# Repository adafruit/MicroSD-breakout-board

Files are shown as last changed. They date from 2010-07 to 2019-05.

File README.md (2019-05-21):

## Adafruit MicroSD breakout board PCB
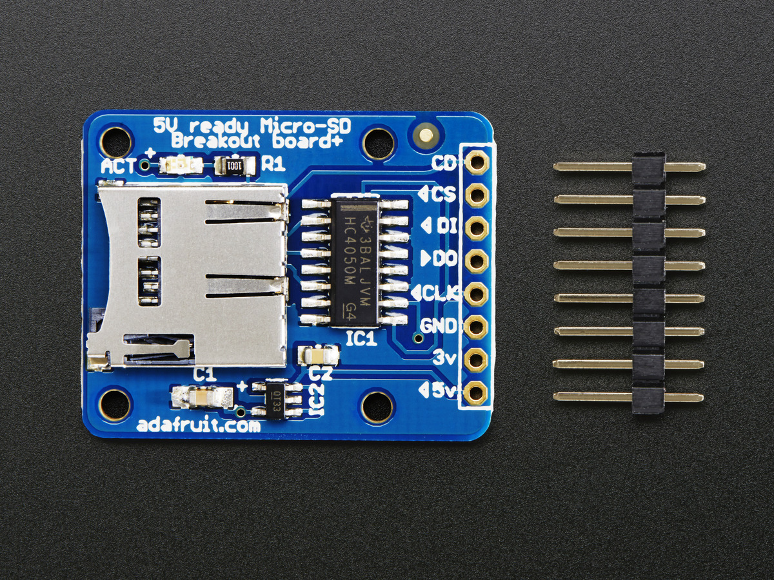
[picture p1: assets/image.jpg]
<a href="http://www.adafruit.com/products/254"><br/>
Click here to purchase one from the Adafruit shop</a>

Not just a simple breakout board, this microSD adapter goes the extra mile - designed for ease of use.

- Onboard 5v->3v regulator provides 150mA for power-hungry cards
- 3v level shifting means you can use this with ease on either 3v or 5v systems
- Uses a proper level shifting chip, not resistors: less problems, and faster read/write access
- Use 3 or 4 digital pins to read and write 2Gb+ of storage!
- Activity LED lights up when the SD card is being read or written
- Four #2 mounting holes
- Push-push socket with card slightly over the edge of the PCB so its easy to insert and remove
- Comes with 0.1" header (unattached) so you can get it on a breadboard or use wires - your choice
- Tested and assembled here at the Adafruit factory
- Works great with Arduino, with tons of example code and wiring diagrams

This repo contains the PCB files for the Adafruit SPI Micro SD (transflash) breakout board

### License

Adafruit invests time and resources providing this open source design, please support Adafruit and open-source hardware by purchasing products from [Adafruit](https://www.adafruit.com)!

All text above must be included in any redistribution

Designed by Limor Fried/Ladyada for Adafruit Industries.
Creative Commons Attribution/Share-Alike, all text above must be included in any redistribution. 
See license.txt for additional information.

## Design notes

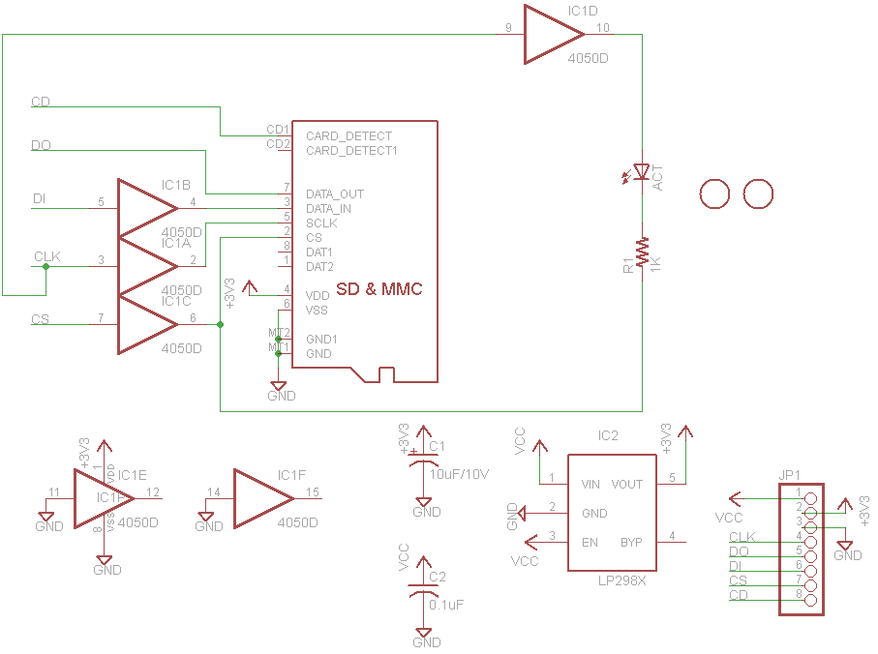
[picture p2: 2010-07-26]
usdbreakout.png

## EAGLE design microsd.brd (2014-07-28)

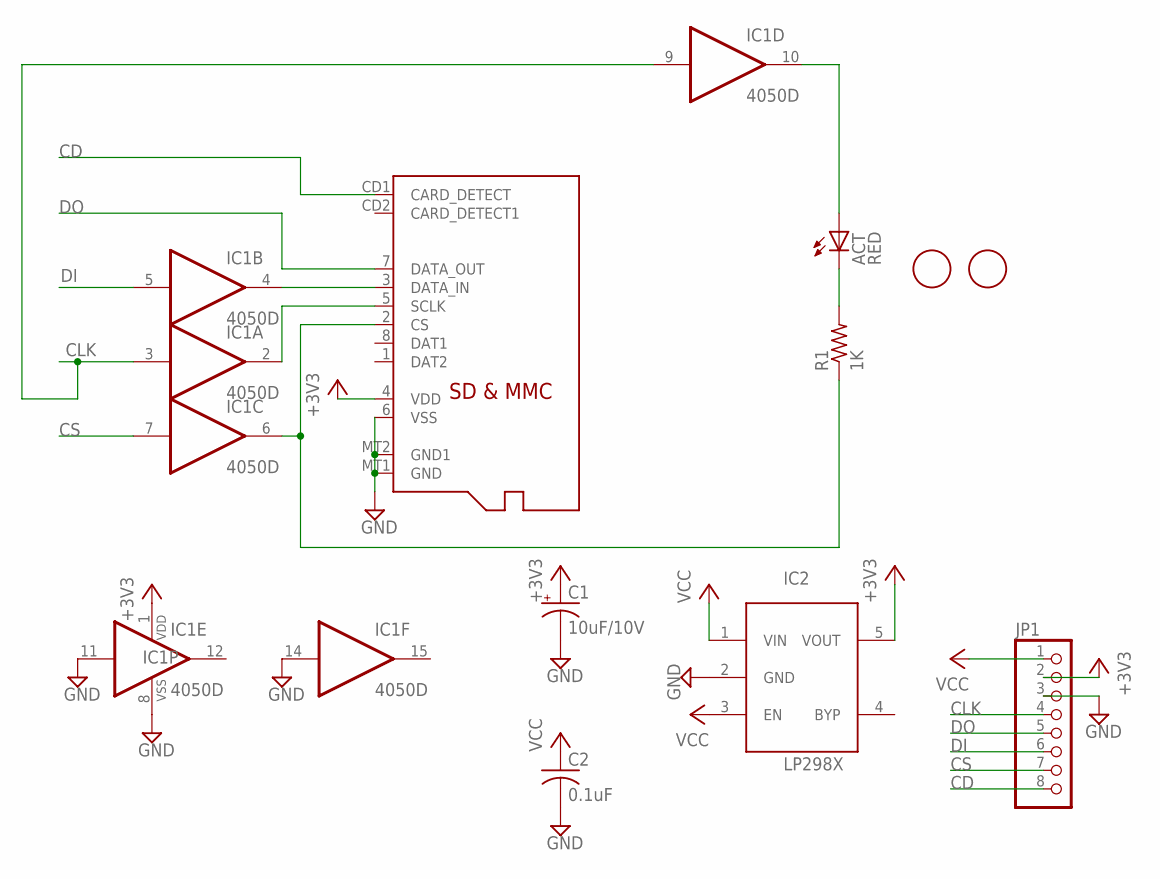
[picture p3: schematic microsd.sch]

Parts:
ACT: RED; CHIP-LED0805
C1: 10uF/10V; A/3216-18R
C2: 0.1uF; C0805K
IC1: 4050D; SO16
IC2: LP298XS; SOT23-5L
JP1: PINHD-1X8BIG; 1X08-BIG
R1: 1K; R0805
U$1, U$2: FIDUCIAL; FIDUCIAL_1MM
X1: MICROSD

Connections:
+3V3: C1.+, IC1.1 (VDD), IC2.5 (VOUT), JP1.2, X1.4 (VDD)
CD: JP1.8, X1.CD1 (CARD_DETECT)
CLK: IC1.3 (I), IC1.9 (I), JP1.4
CS: IC1.7 (I), JP1.7
DI: IC1.5 (I), JP1.6
DO: JP1.5, X1.7 (DATA_OUT)
GND: C1.-, C2.2, IC1.8 (VSS), IC1.11 (I), IC1.14 (I), IC2.2 (GND), JP1.3, X1.6 (VSS), X1.MT1 (GND), X1.MT2 (GND1)
unnamed: ACT.A, IC1.10 (O)
unnamed: IC1.2 (O), X1.5 (SCLK)
unnamed: IC1.6 (O), R1.1, X1.2 (CS)
unnamed: ACT.C, R1.2
unnamed: IC1.4 (O), X1.3 (DATA_IN)
VCC: C2.1, IC2.1 (VIN), IC2.3 (EN), JP1.1

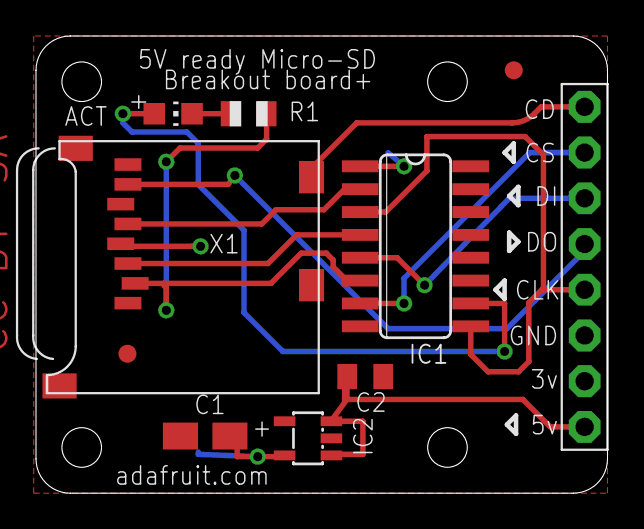
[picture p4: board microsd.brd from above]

Board: 2 copper layers, 31.8 x 25.4 mm, 10 parts (0 on the bottom side), 13 nets.

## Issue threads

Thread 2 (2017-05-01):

Hand or machine assembled?

maurbeck, 2017-05-01:
Is the SD slot machine-solderable? Or do the tiny pins through the open holes in the SD slot have to be soldered by hand?

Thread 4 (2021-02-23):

Is there a footprint for KiCad?

cbmeeks, 2021-02-23:
I use KiCad and was wondering if there was an easy way to import this board into it?  I would rather not have to create a custom footprint if I don't have to.

Thanks.

dherrada, 2021-02-23:
@cbmeeks I haven't ever used KiCad so I don't actually know if this will work but maybe try doing this: https://support.snapeda.com/en/articles/2911566-how-to-import-sch-brd-into-kicad

Closed 2021-02-25.

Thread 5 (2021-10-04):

Poor documentation on capacitors

rickdgray, 2021-10-04:
https://learn.adafruit.com/adafruit-micro-sd-breakout-board-card-tutorial/download

The schematic lists C2 as 0.1 microfarad and the capacitance of C3 is undocumented. Furthermore, the silkscreen labels them as C1 and C2.

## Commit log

2010-07-26 files and schematic image
    [microsd.brd, microsd.sch]
2014-07-28 re-save as eagle 6
    [microsd.brd, microsd.sch]

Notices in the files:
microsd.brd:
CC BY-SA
